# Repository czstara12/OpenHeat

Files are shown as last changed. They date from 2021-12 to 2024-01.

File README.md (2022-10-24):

# OpenHeat：开源智能加热台

# 添加&修改内容

1. 添加 [MAX6675代码](https://github.com/adafruit/MAX6675-library)，获取K型热电偶温度，可正常使用。

2. 增加外壳文件，修改自 *酒鬼橘子* 。

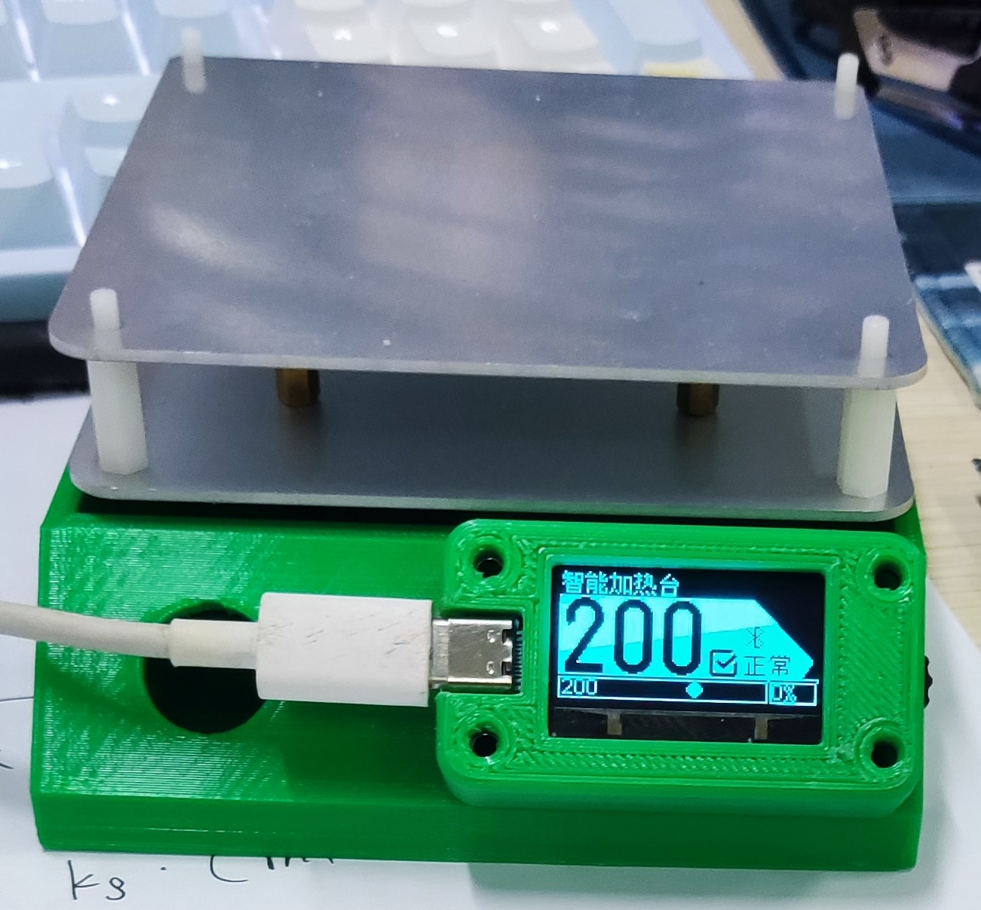
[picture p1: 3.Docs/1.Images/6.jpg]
   

3. 为配套该外壳，增加100x100的热床和中间夹层。已上传至立创EDA，方便白嫖，跳转链接为： [OpenHeat热床](https://oshwhub.com/u_16/open-heat-hot-bed) 。文件修改自 *酒鬼橘子* 。

   

   

4. 更新 [U8g2库](https://github.com/olikraus/U8g2_Arduino)，如后续仍出现无法显示，串口提示 `Bus is in Slave Mode` ，大概率是U8g2库问题，更新到最新版库即可。

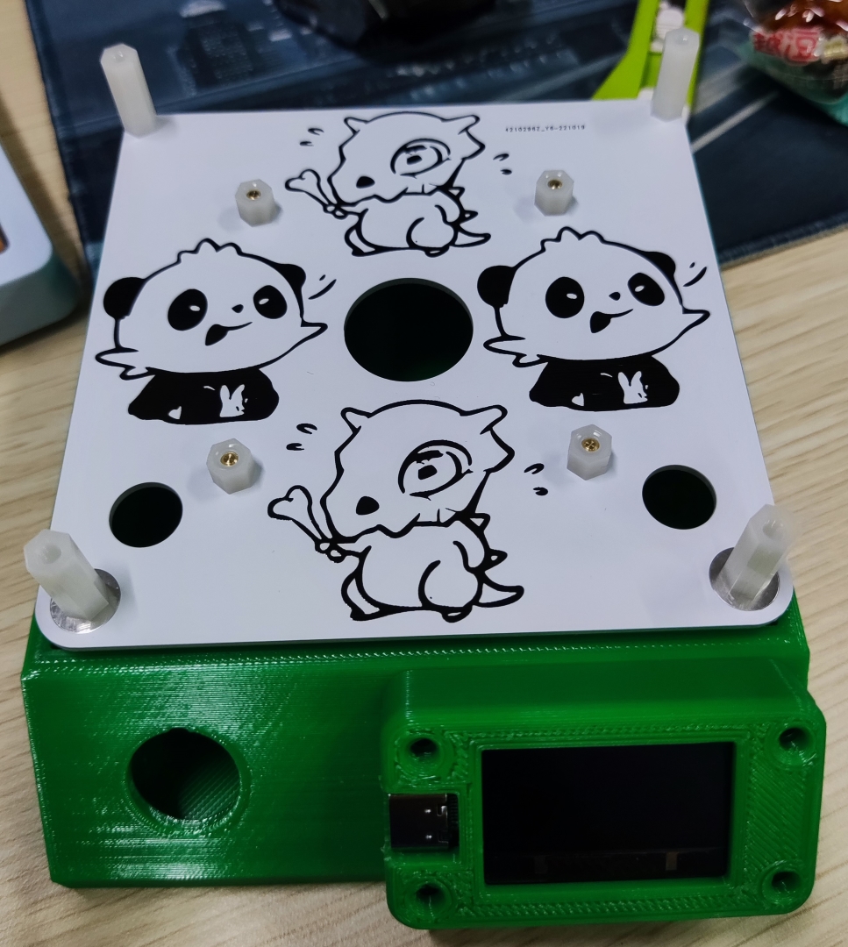
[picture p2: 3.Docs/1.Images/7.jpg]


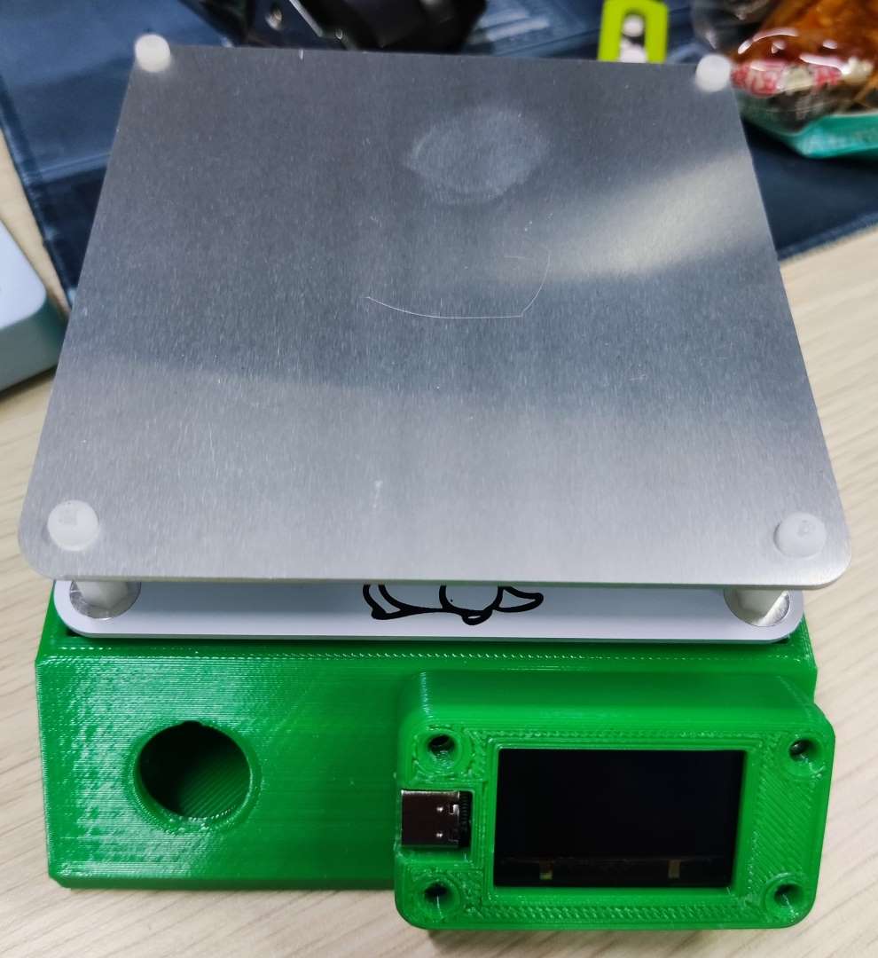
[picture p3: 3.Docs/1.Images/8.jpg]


# 以下为稚晖君原版内容

> 用于PCB回流焊的实用加热台，比较炫酷，可能目前市面上 **颜值最高** & **功能最强** 的加热台。

**参数：** 硬件方面基于`ESP32PICO-D4`芯片，输入电源`24V/10A`，最大功率200W，加热温度最高300℃；带蓝牙功能，***后续有空的话我会开发手机APP用于设置升温曲线*** 。

## 21-9-17 修复说明：



---

## 关于本项目



* 本项目参考了 [createskyblue](https://gitee.com/createskyblue) / [OpenT12](https://gitee.com/createskyblue/OpenT12)开源T12电烙铁项目的固件，感谢这位同学设计的优秀交互动画体验，UI设计深得我心哈哈~

* 另外铝基板热床的设计采用了[MRobot-Origin](https://github.com/MRobot-Origin)/ [GS_Hbed](https://github.com/MRobot-Origin/GS_Hbed)同学的分型曲线设计，非常有创意~

## 使用说明

#### 1. 打样说明

直接用Hardware文件夹里的Gerber文件打样即可：主控制器为4层PCB，无特殊工艺要求；热床为铝基板PCB，可以在嘉立创打样。

> 铝基板是一种专门用来散热的PCB板材，大家看到的很多大功率LED灯珠就是这种，前阵子嘉立创开放了铝基板打样业务，还很便宜。所以相比于设计一个金属块做热床，这种方式不但成本低而且美观实用。

另外其实还有一块可选两层板作为固定件的，这个我还没来得及设计，也很简单，大家可以根据自己情况画一个，或者直接3D打印结构件固定也行。

#### 2. 固件说明

固件我这边是基于PlatformIO移植的，所以大家用这个平台的话直接打开下载就行了；如果是用Arduino IDE的话，先安装Library里面的库文件，然后一样下载。

固件库没有完全配置完成（因为原版固件是设计为电烙铁使用的），晚些我硬件都就位了会调试好固件供大家直接下载。

#### 3. 关于结构件

这个我也还在设计，我的风格肯定是以美观小巧为主，大家可以等我放出3D打印文件。

#### 4. 关于温度传感器

我这边是用的是K型热电偶，在PCB上已经集成了采集芯片，需要自己买一个表贴式的K型热电偶连接到板子下方的两个焊盘。

> 注意热电偶和热床的接触要绝缘，用高温胶带隔一下就行。另外热电偶是有极性的，如果发现加热后温度反而下降说明接反了。
>
> 现在代码中还没有加热电偶的代码，晚一点有空了会调好完整固件。大家自己添加也很容易，MAX6675使用SPI驱动，Arduino平台有很多例程。

#### 5. 关于元器件BOM

**注意！！！** C9电容一定要选耐压足够的，因为是并联到24V的VCC上，如果耐压不够短路的话可以看到烟花！！

#### 接线图



## 欢迎star支持 :D









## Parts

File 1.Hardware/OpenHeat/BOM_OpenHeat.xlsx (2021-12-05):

Comment | Description | Designator | Footprint | LibRef | Quantity
OLED-12864 | 显示屏 | 1 | OLED-12864-1.3-TOP | OLED-12864 | 1
RAINSUN |  | A1 | ANT-Rainsun-AN5120 | ANT-Rainsun-AP5120 | 1
10uF | Capacitor | C1, C8, C9, C12, C16, C18 | CAP_0402 | 电容-0402 | 6
0.1uF | Capacitor | C2, C3, C5, C7, C10, C11, C17 | CAP_0402 | 电容-0402 | 7
100pF | Capacitor | C4 | CAP_0402 | 电容-0402 | 1
100uF | Capacitor | C6 | 1206-CAP | 电容-1206 | 1
10nF | Capacitor | C13 | CAP_0402 | 电容-0402 | 1
1uF | Capacitor | C14, C15, C19 | CAP_0402 | 电容-0402 | 3
270pF | Capacitor | C20 | CAP_0402 | 电容-0402 | 1
SS54 | Diode | D1 | DO-214AC | Diode_SMA | 1
SMBJ28CA |  | D2 | SMBJ-CA_MFG | SMBJ28CA | 1
二极管-5819W | 40V | D3, D4, D5 | SOD-323 | 二极管-5819W | 3
6.8uH |  | L1 | IND-201612 | 电感-201612 | 1
BC847BVC-7 |  | Q1 | SOT563-6 | BC847BVC-7 | 1
NTMFS5C628NLT | MOSFET N-CH 60V SO8FL | Q2, Q4, Q5 | SO8FL | NTMFS5C628NLT | 3
AO3400A | N-MOS | Q3 | SOT23-3 | AO3400A | 1
10K | Resistor | R1, R3, R5, R9, R13, R14, R18, R19, R20, R21, R26, R27, R28, R29 | RES_0402 | 电阻-0402 | 14
0R | Resistor | R2, R22 | RES_0402 | 电阻-0402 | 2
100R | Resistor | R4 | RES_0402 | 电阻-0402 | 1
1.8K | Resistor | R6 | RES_0402 | 电阻-0402 | 1
12K | Resistor | R7, R10 | RES_0402 | 电阻-0402 | 2
1M | Resistor | R8, R24 | RES_0402 | 电阻-0402 | 2
5.1K | Resistor | R11, R12 | RES_0402 | 电阻-0402 | 2
1K | Resistor | R15, R30 | RES_0402 | 电阻-0402 | 2
2.2R | Resistor | R16, R23, R31 | RES_0402 | 电阻-0402 | 3
100K | Resistor | R17, R25, R32 | RES_0402 | 电阻-0402 | 3
Rotary Encoder |  | SW1 | SIQ-02FVS3 | Rotary Encoder | 1
CP2102 | USB转TTL | U1 | QFN-28 | CP2102 | 1
ME3116 | DC-DC | U2 | SOT23-6 | ME3116 | 1
LP2992 3V3 | LDO | U3 | SOT23-5 | LP2992 | 1
ESP32_SIP |  | U4 | QFN-48_7X7 | ESP32-PICO | 1
MAX6675ISA | IC THERMOCOUP TO DGTL 8-SOIC | U5 | SO-8 | MAX6675ISA | 1
DET402 |  | U6 | DET402 | DET402 | 1
Type-C |  | USB1 | Type-C-TOP | USB-Type-C-TOP | 1
S8050 | Surface mount NPN transistor, package SOT-23 | VT1 | SMT_TRIODE_NPN | SMT_TRIODE_NPN | 1

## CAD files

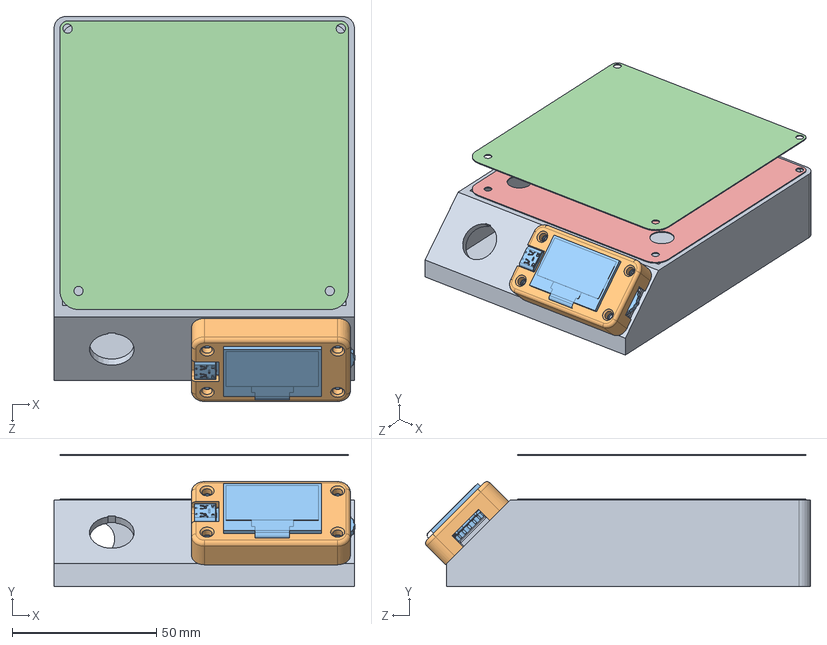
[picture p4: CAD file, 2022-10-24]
4.CAD-Model/OPEN HEAT加热台/OPEN HEAT装配体.SLDASM
104.2 x 45.8 x 133.3 mm
OPEN HEAT主体
OPEN HEAT控制器外壳
OpenHeat
100mm²HotBeb
中间层

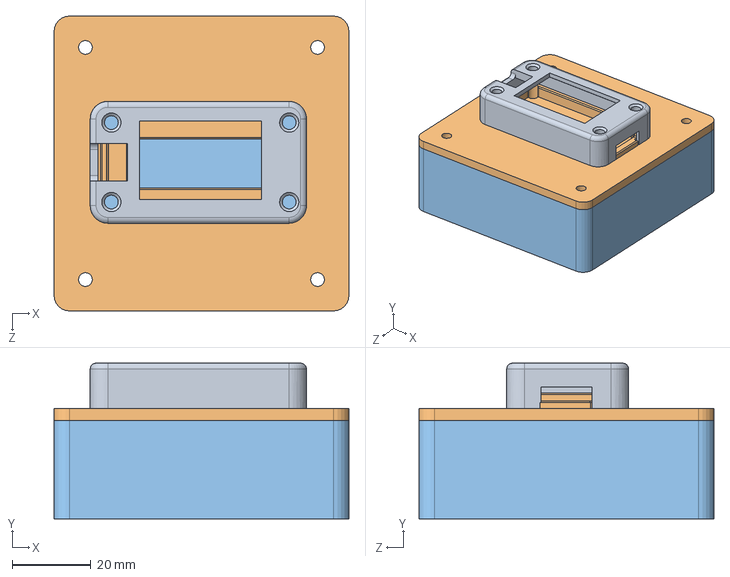
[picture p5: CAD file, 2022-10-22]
4.CAD-Model/温控外壳/控制器壳装配体.SLDASM
75.0 x 39.6 x 75.0 mm
控制器壳座
线夹

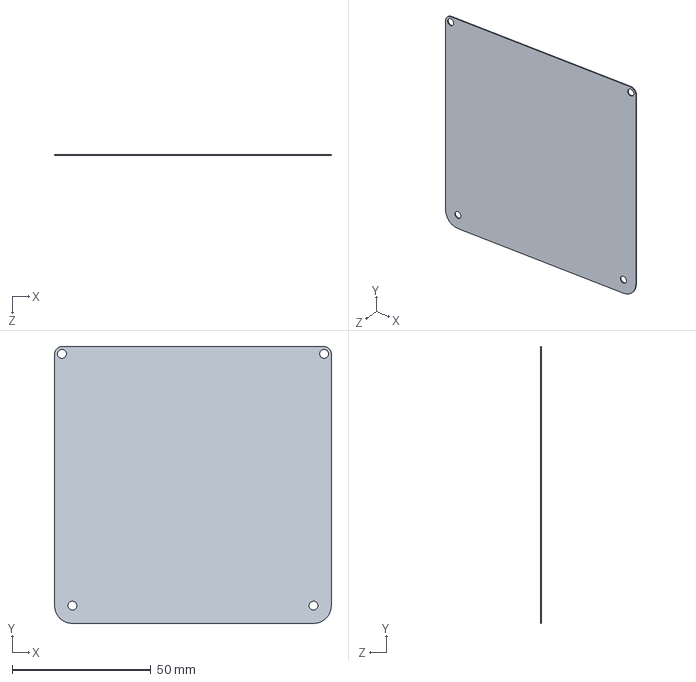
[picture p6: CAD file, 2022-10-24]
4.CAD-Model/PCB_3D/100mm²HotBeb.SLDPRT
99.9 x 99.9 x 0.411 mm

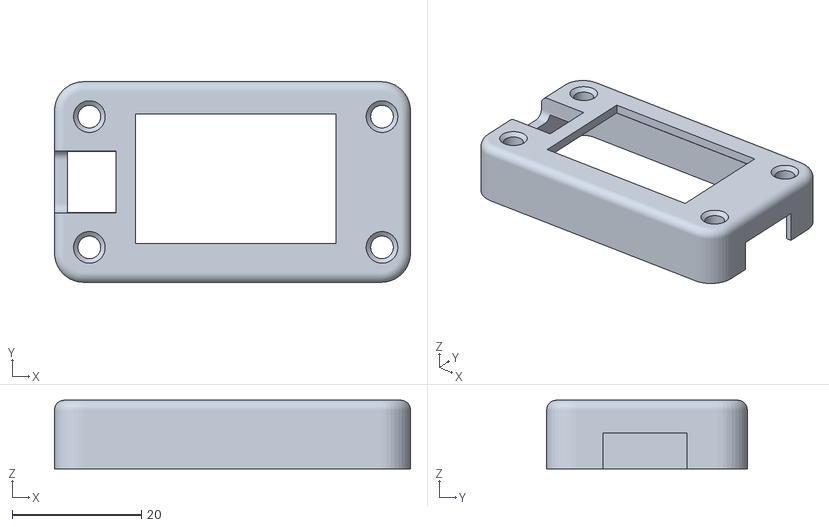
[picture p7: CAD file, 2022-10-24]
4.CAD-Model/STL/OPEN HEAT控制器外壳.STL
55.0 x 31.0 x 10.6

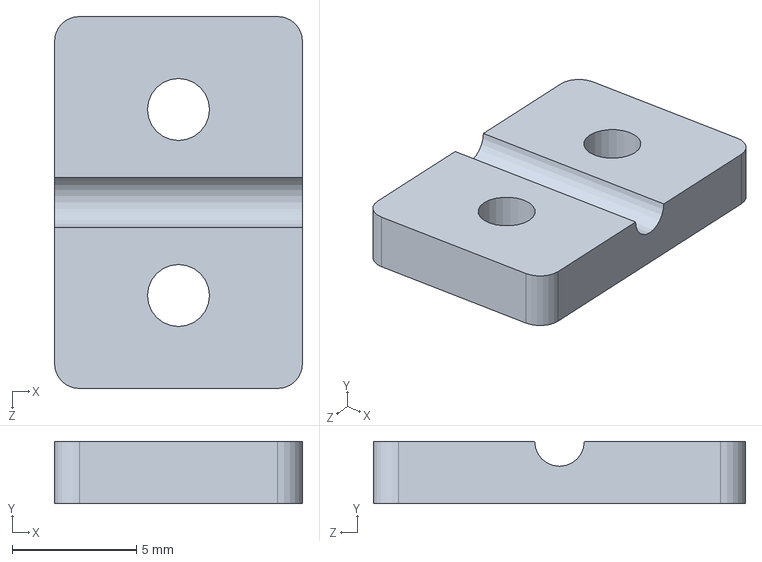
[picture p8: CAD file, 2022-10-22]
4.CAD-Model/温控外壳/线夹.SLDPRT
10.0 x 2.50 x 15.0 mm

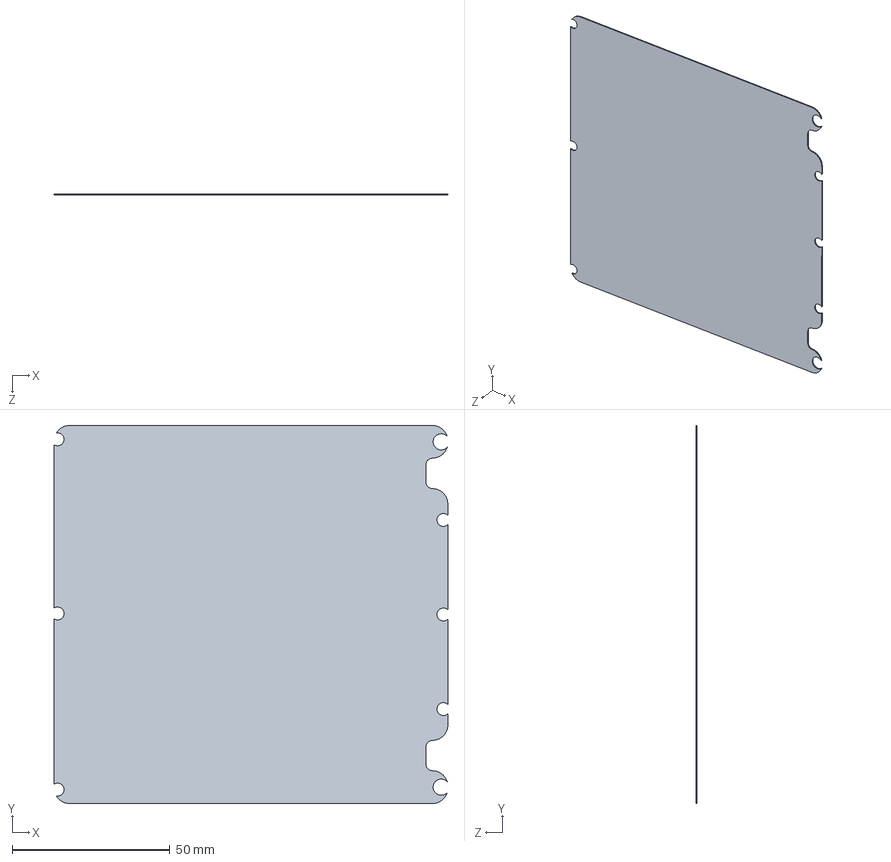
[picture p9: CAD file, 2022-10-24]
4.CAD-Model/PCB_3D/HotBed-24V_修改.SLDPRT
125.0 x 120.0 x 0.411 mm

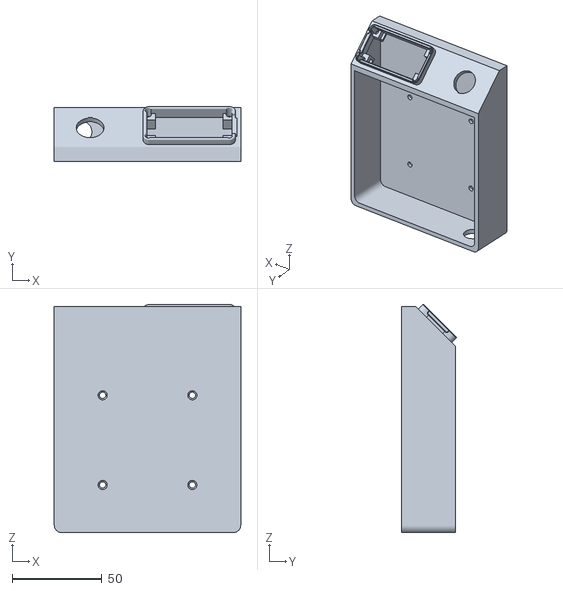
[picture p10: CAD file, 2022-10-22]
4.CAD-Model/STL/OPEN HEAT主体.STL
104.0 x 30.6 x 127.1

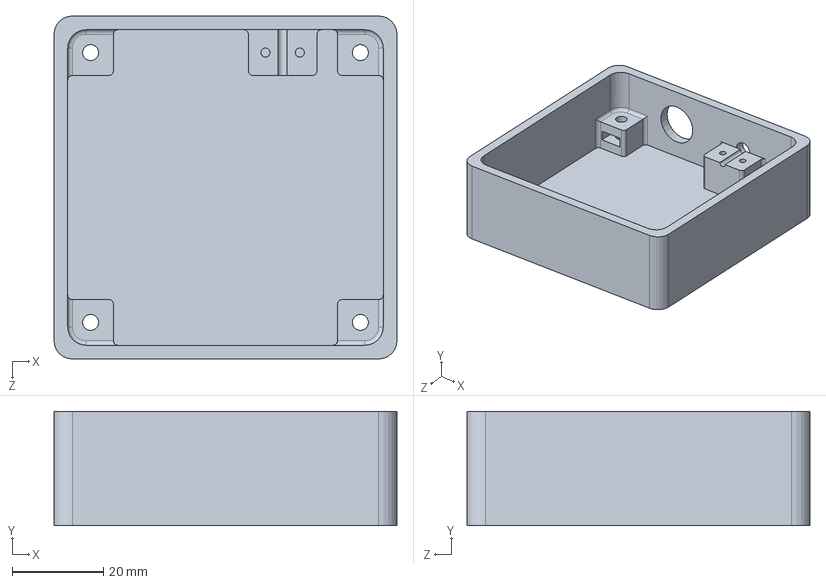
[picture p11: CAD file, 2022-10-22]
4.CAD-Model/温控外壳/控制器壳座.SLDPRT
75.0 x 25.0 x 75.0 mm

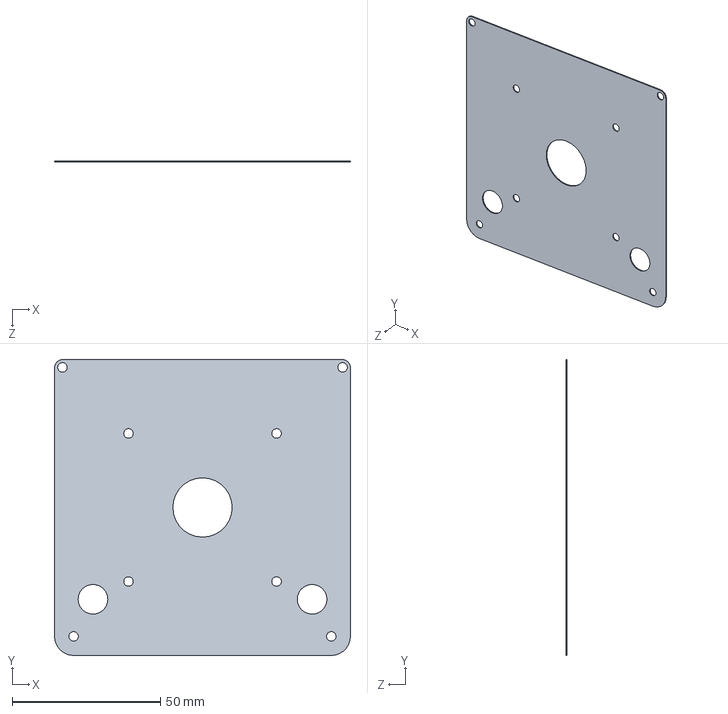
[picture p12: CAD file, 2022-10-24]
4.CAD-Model/PCB_3D/中间层.SLDPRT
99.9 x 99.9 x 0.411 mm

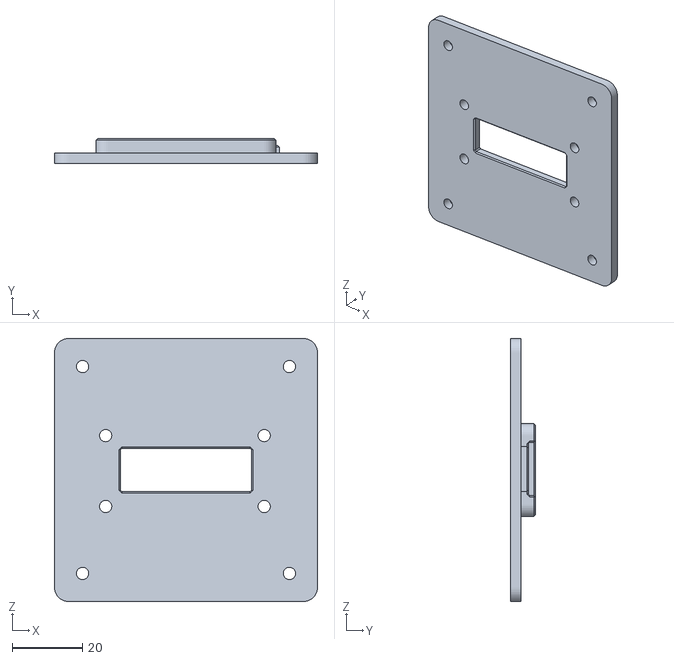
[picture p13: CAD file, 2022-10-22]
4.CAD-Model/STL/控制器壳盖.STL
75.0 x 7.00 x 75.0

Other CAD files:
4.CAD-Model/OPEN HEAT加热台/OPEN HEAT控制器外壳.SLDPRT
4.CAD-Model/OPEN HEAT加热台/OPEN HEAT主体.SLDPRT
4.CAD-Model/温控外壳/控制器壳盖.SLDPRT
4.CAD-Model/STL/线夹.STL
4.CAD-Model/STL/控制器壳座.STL

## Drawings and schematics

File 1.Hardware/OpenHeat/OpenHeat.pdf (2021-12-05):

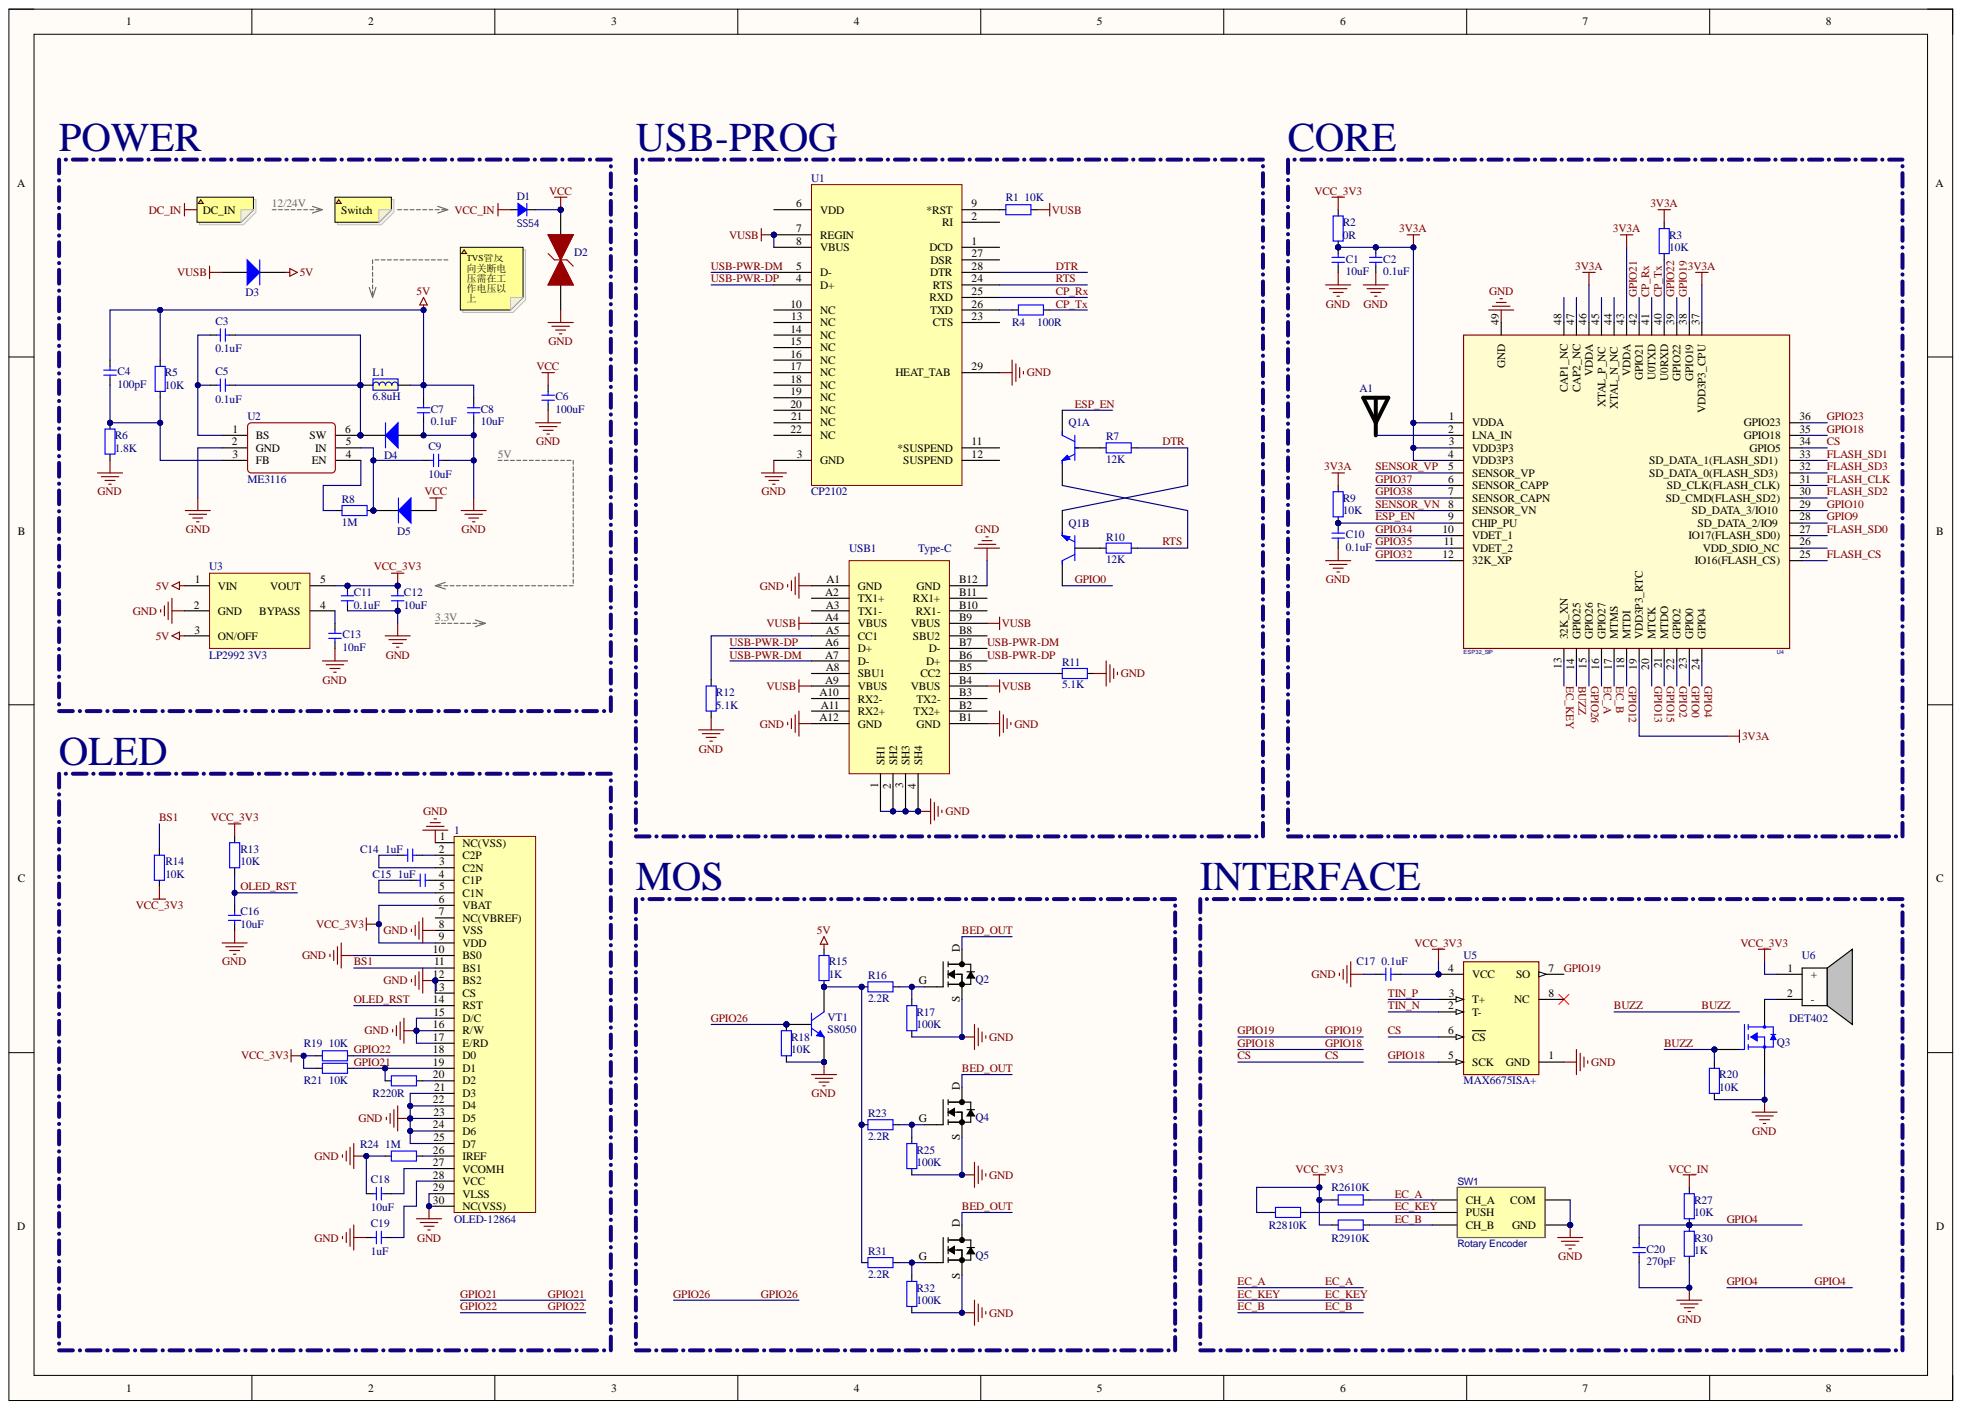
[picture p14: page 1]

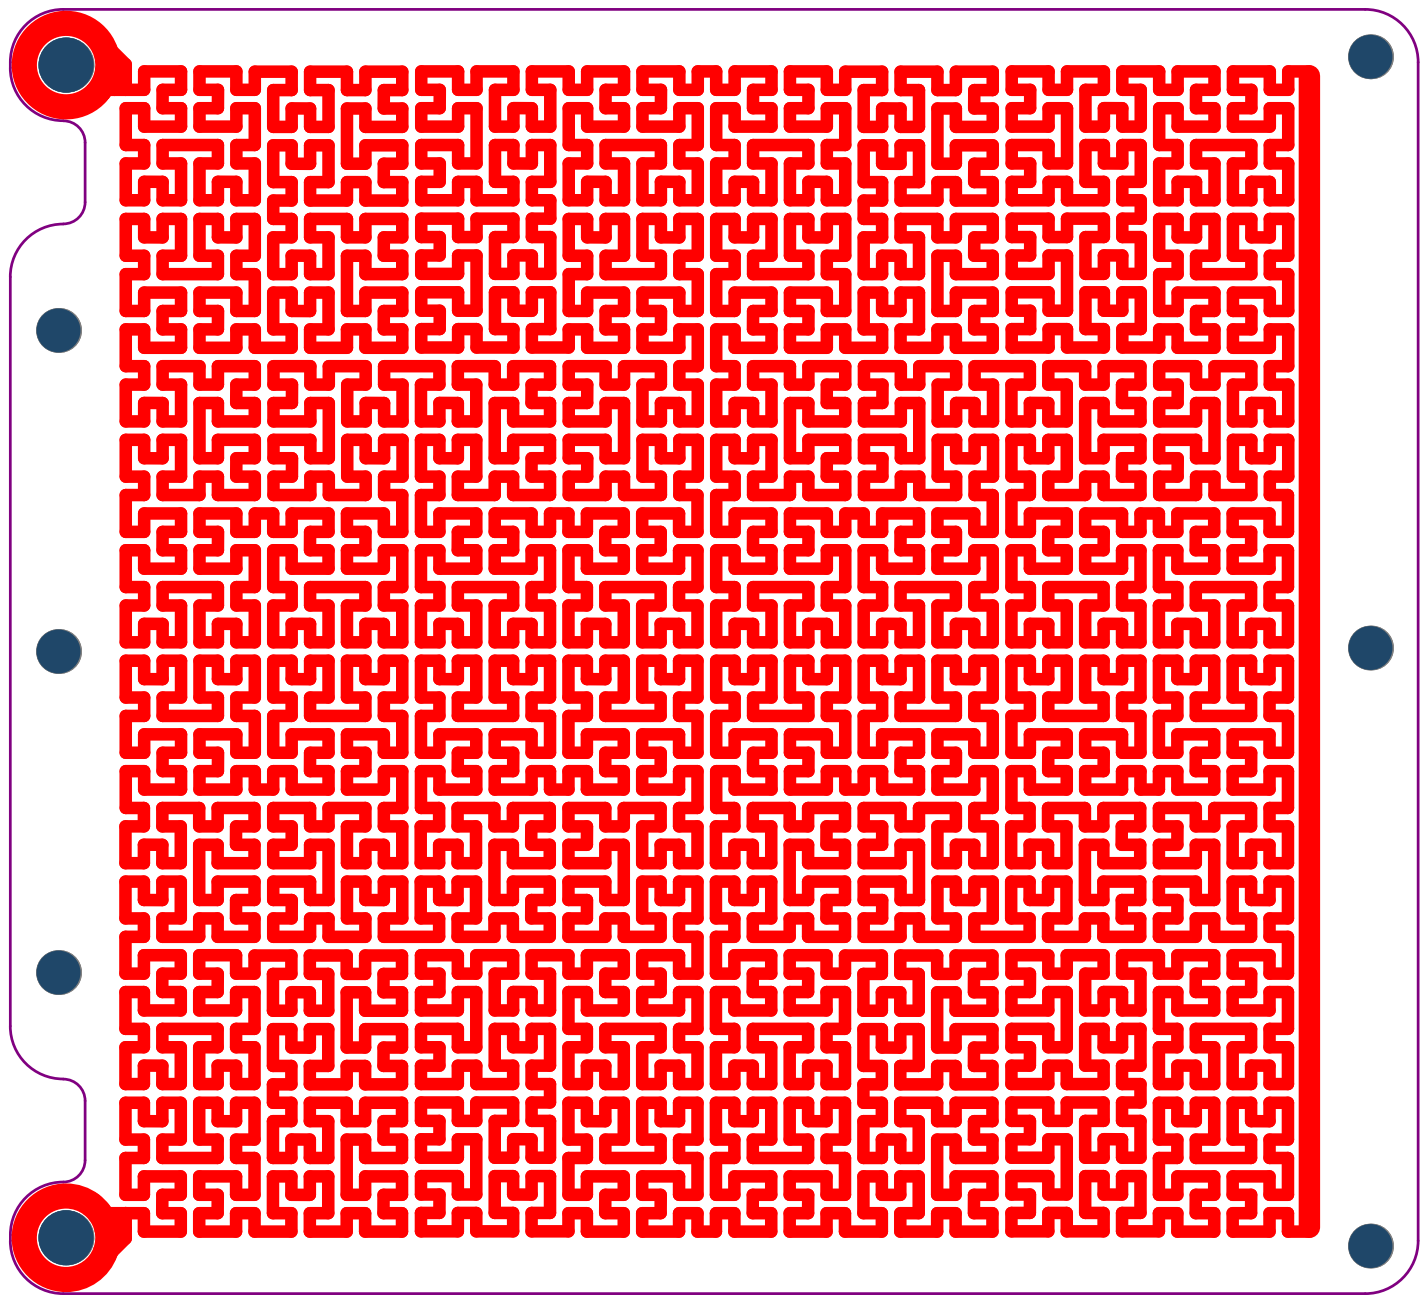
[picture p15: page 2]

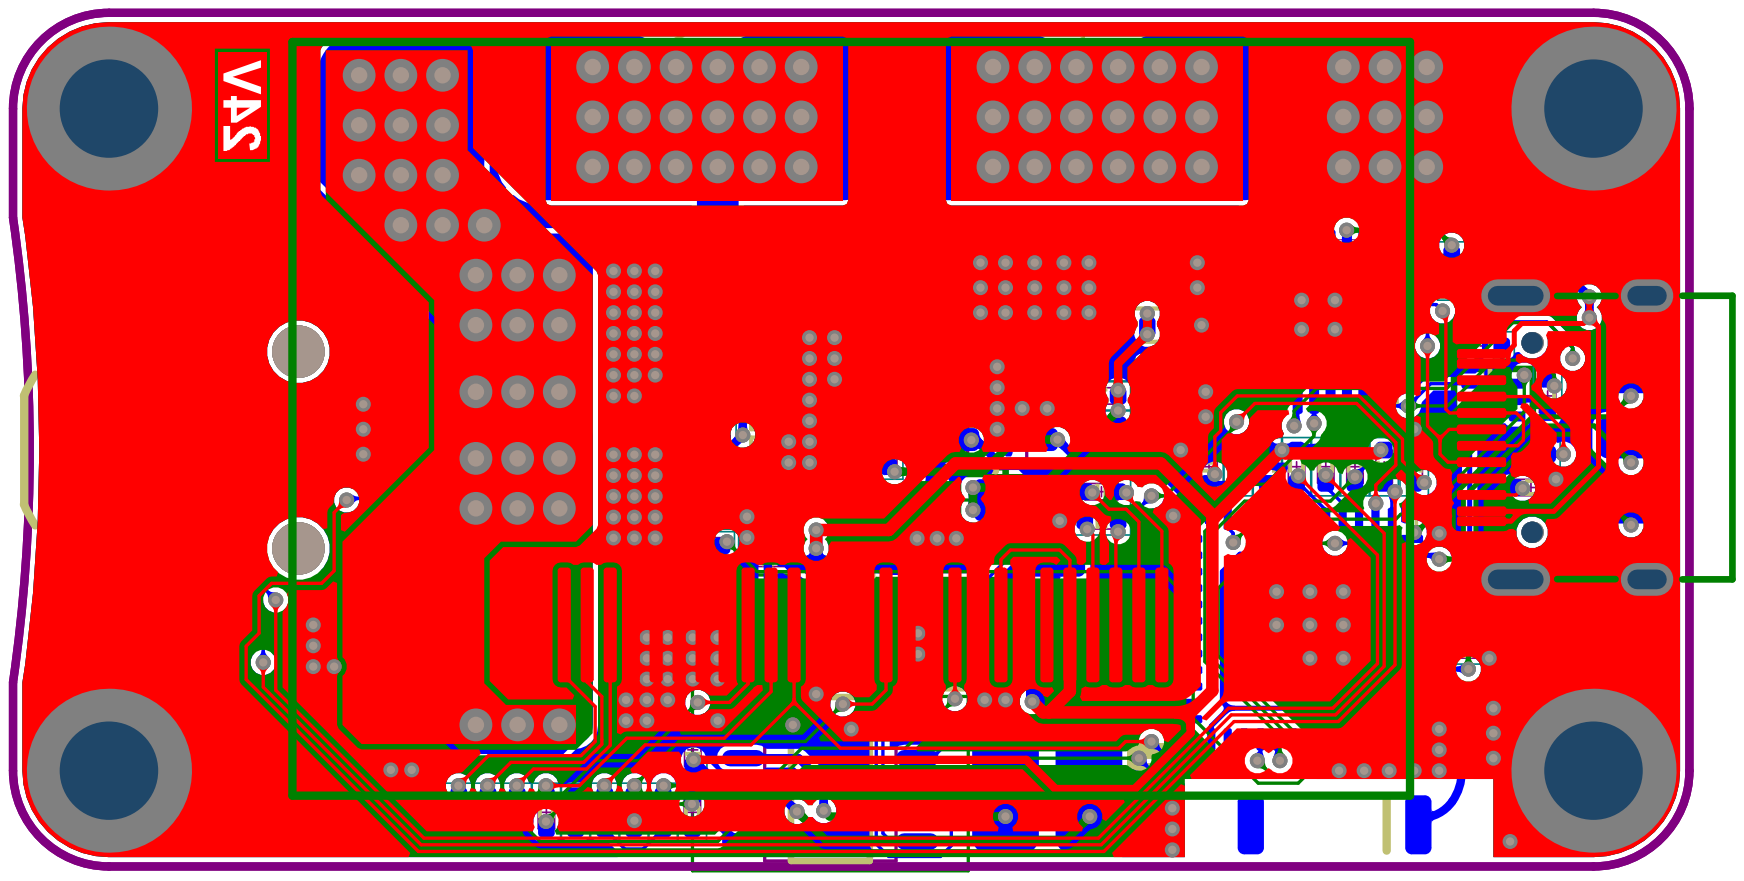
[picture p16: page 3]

Comment | Description | Designator | Footprint | LibRef | Quantity
OLED-12864 | 显示屏 | 1 | OLED-12864-1.3-TOP | OLED-12864 | 1
RAINSUN | | A1 | ANT-Rainsun-AN5120 | ANT-Rainsun-AP5120 | 1
10uF | Capacitor | C1, C8, C9, C12, C16, C18 | CAP_0402 | 电容-0402 | 6
0.1uF | Capacitor | C2, C3, C5, C7, C10, C11, C17 | CAP_0402 | 电容-0402 | 7
100pF | Capacitor | C4 | CAP_0402 | 电容-0402 | 1
100uF | Capacitor | C6 | 1206-CAP | 电容-1206 | 1
10nF | Capacitor | C13 | CAP_0402 | 电容-0402 | 1
1uF | Capacitor | C14, C15, C19 | CAP_0402 | 电容-0402 | 3
270pF | Capacitor | C20 | CAP_0402 | 电容-0402 | 1
SS54 | Diode | D1 | DO-214AC | Diode_SMA | 1
SMBJ28CA | | D2 | SMBJ-CA_MFG | SMBJ28CA | 1
二极管-5819W | 40V | D3, D4, D5 | SOD-323 | 二极管-5819W | 3
6.8uH | | L1 | IND-201612 | 电感-201612 | 1
BC847BVC-7 | | Q1 | SOT563-6 | BC847BVC-7 | 1
NTMFS5C628NLT | MOSFET N-CH 60V SO8FL | Q2, Q4, Q5 | SO8FL | NTMFS5C628NLT | 3
AO3400A | N-MOS | Q3 | SOT23-3 | AO3400A | 1
10K | Resistor | R1, R3, R5, R9, R13, R14, R18, R19, R20, R21, R26, R27, R28, R29 | RES_0402 | 电阻-0402 | 14
0R | Resistor | R2, R22 | RES_0402 | 电阻-0402 | 2
100R | Resistor | R4 | RES_0402 | 电阻-0402 | 1
1.8K | Resistor | R6 | RES_0402 | 电阻-0402 | 1
12K | Resistor | R7, R10 | RES_0402 | 电阻-0402 | 2
1M | Resistor | R8, R24 | RES_0402 | 电阻-0402 | 2
5.1K | Resistor | R11, R12 | RES_0402 | 电阻-0402 | 2
1K | Resistor | R15, R30 | RES_0402 | 电阻-0402 | 2
2.2R | Resistor | R16, R23, R31 | RES_0402 | 电阻-0402 | 3
100K | Resistor | R17, R25, R32 | RES_0402 | 电阻-0402 | 3
Rotary Encoder | | SW1 | SIQ-02FVS3 | Rotary Encoder | 1
CP2102 | USB转TTL | U1 | QFN-28 | CP2102 | 1
ME3116 | DC-DC | U2 | SOT23-6 | ME3116 | 1
LP2992 3V3 | LDO | U3 | SOT23-5 | LP2992 | 1
ESP32_SIP | | U4 | QFN-48_7X7 | ESP32-PICO | 1
MAX6675ISA | IC THERMOCOUP TO DGTL 8-SOIC | U5 | SO-8 | MAX6675ISA | 1
DET402 | | U6 | DET402 | DET402 | 1
Type-C | | USB1 | Type-C-TOP | USB-Type-C-TOP | 1
S8050 | Surface mount NPN transistor, package SOT-23 | VT1 | SMT_TRIODE_NPN | SMT_TRIODE_NPN | 1

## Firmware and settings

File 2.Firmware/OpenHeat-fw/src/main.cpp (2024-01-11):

#include <Arduino.h>
#include "OpenT12.h"

BluetoothSerial SerialBT;
#if !defined(CONFIG_BT_ENABLED) || !defined(CONFIG_BLUEDROID_ENABLED)
#error Bluetooth is not enabled! Please run `make menuconfig` to and enable it
#endif

int thermoDO = 19;
int thermoCS = 5;
int thermoCLK = 18;

MAX6675 thermocouple(thermoCLK, thermoCS, thermoDO);
OneButton RButton(BUTTON_PIN, true);
U8G2_SH1106_128X64_NONAME_F_HW_I2C Disp(U8G2_R0, /* reset=*/U8X8_PIN_NONE, /* clock=*/22, /* data=*/21);
PID MyPID(&TipTemperature, &PID_Output, &PID_Setpoint, aggKp, aggKi, aggKd, DIRECT);
/////////////////////////////////////////////////////////////////

char *TipName = "文件系统错误：请上报";

float BootTemp = 200; // 开机温度          (°C)
float SleepTemp = 80; // 休眠温度          (°C)
float BoostTemp = 50; // 爆发模式升温幅度   (°C)

float ShutdownTime = 0;         // 关机提醒              (分)
float SleepTime = 10;           // 休眠触发时间          (分)
float ScreenProtectorTime = 60; // 屏保在休眠后的触发时间(秒)
float BoostTime = 60;           // 爆发模式持续时间      (秒)

bool SYS_Ready = false;
// 烙铁头事件
bool TipInstallEvent = true;
bool TipCallSleepEvent = false;
// 到温提示音播放完成
bool TempToneFlag = false;
// 休眠后屏保延迟显示标志
bool SleepScreenProtectFlag = false;
// 温控系统状态
bool ERROREvent = false;
bool ShutdownEvent = false;
bool SleepEvent = false;
bool BoostEvent = false;
bool UnderVoltageEvent = false;
// PWM控制状态
bool PWM_WORKY = false;

uint8_t PIDMode = true;
uint8_t Use_KFP = true;
uint8_t PanelSettings = PANELSET_Detailed;
uint8_t ScreenFlip = false;
uint8_t SmoothAnimation_Flag = true;
float ScreenBrightness = 128;
uint8_t OptionStripFixedLength_Flag = false;

uint8_t Volume = true;
uint8_t RotaryDirection = false;
uint8_t HandleTrigger = HANDLETRIGGER_VibrationSwitch;

double SYS_Voltage = 3.3;
float UndervoltageAlert = 3;
char BootPasswd[20] = {0};
uint8_t Language = LANG_Chinese;
uint8_t MenuListMode = false;

float ADC_PID_Cycle = 100;
float MAX6675Temp_Cycle = 300; // MAX6675温度采集周期

// 面板状态条
uint8_t TempCTRL_Status = TEMP_STATUS_OFF;
uint8_t *C_table[] = {c1, c2, c3, Lightning, c5, c6, c7};
char *TempCTRL_Status_Mes[] = {
    "错误",
    "停机",
    "休眠",
    "提温",
    "正常",
    "加热",
    "维持",
};

// 系统信息
uint64_t ChipMAC;
char ChipMAC_S[19] = {0};
char CompileTime[20];

/////////////////////////////////////////////////////////////////

// 先初始化硬件->显示LOGO->初始化软件
void setup()
{
    // 关闭中断
    // noInterrupts();

    ////////////////////////////初始化硬件/////////////////////////////
    // 获取系统信息
    ChipMAC = ESP.getEfuseMac();
    sprintf(CompileTime, "%s %s", __DATE__, __TIME__);
    for (uint8_t i = 0; i < 6; i++)
        sprintf(ChipMAC_S + i * 3, "%02X%s", ((uint8_t *)&ChipMAC)[i], (i != 5) ? ":" : "");

    // 初始化串口
    Serial.begin(115200);

    // 初始化GPIO
    BeepInit(); // 蜂鸣器

    pinMode(POWER_ADC_PIN, INPUT); // 主电压分压检测ADC

    // 初始化烙铁头
    TipControlInit();

    // 初始化编码器
    sys_RotaryInit();

    // 初始化OLED
    Disp.begin();
    Disp.setBusClock(921600); // 设置总线时钟
    Disp.enableUTF8Print();   // 启用 UTF8打印
    Disp.setFontDirection(0); // 设置字体方向
    Disp.setFontPosTop();
    Disp.setFont(u8g2_font_wqy12_t_gb2312); // 设置字体集
    Disp.setDrawColor(1);                   // 设置绘制颜色
    Disp.setFontMode(1);

    ////////////////////////////初始化软件/////////////////////////////
    // 显示启动信息
    // ShowBootMsg();

    // 启动文件系统，并读取存档
    FilesSystemInit();

    // 初始化命令解析器
    shellInit();

    // 初始化蓝牙（可选）
    BLE_Init();

    SetSound(BootSound); // 播放音效

    // 初始化UI
    System_UI_Init();

    // 首次启动的时候根据启动温度配置，重新设定目标温度
    sys_Counter_SetVal(BootTemp);

    // 载入烙铁头配置
    LoadTipConfig();

    // 显示Logo
    // EnterLogo();

    // 开机密码
    while (!EnterPasswd())
    {
        Pop_Windows("身份验证失败");
    }
    SYS_Ready = true;
}

void loop()
{
    // 获取按键
    sys_KeyProcess();

    if (!Menu_System_State)
    {
        // 温度闭环控制
        TemperatureControlLoop();
        // 更新系统事件：：系统事件可能会改变功率输出
        TimerEventLoop();
    }

    // 更新状态码
    SYS_StateCode_Update();
    // 设置输出功率
    SetPOWER(PID_Output);

    // 刷新UI
    System_UI();
}
/**
 * @description: 计算主电源电压
 * @param {*}
 * @return 主电源电压估计值
 */
double Get_MainPowerVoltage(void)
{
    // uint16_t POWER_ADC = analogRead(POWER_ADC_PIN);
    double TipADC_V_R2 = analogReadMilliVolts(POWER_ADC_PIN) / 1000.0;
    // double   TipADC_V_R2 = ESP32_ADC2Vol(POWER_ADC);
    double TipADC_V_R1 = (TipADC_V_R2 * POWER_ADC_VCC_R1) / POWER_ADC_R2_GND;

    SYS_Voltage = TipADC_V_R1 + TipADC_V_R2;
    return SYS_Voltage;
}

void SYS_Reboot(void)
{
    ESP.restart();
}

void About(void)
{
    // 播放Logo动画
    EnterLogo();
    // 生成项目QRCode
    QRCode qrcode;
    uint8_t qrcodeData[qrcode_getBufferSize(3)];

    switch (Language)
    {
    case LANG_Chinese:
        qrcode_initText(&qrcode, qrcodeData, 3, 0, "https://gitee.com/createskyblue/OpenT12");
        break;

    default:
        qrcode_initText(&qrcode, qrcodeData, 3, 0, "https://github.com/createskyblue/OpenT12");
        break;
    }

    Clear();

    uint8_t x_offset = (SCREEN_COLUMN - qrcode.size * 2) / 2;
    uint8_t y_offset = (SCREEN_ROW - qrcode.size * 2) / 2;

    for (uint8_t y = 0; y < qrcode.size; y++)
        for (uint8_t x = 0; x < qrcode.size; x++)
            if (qrcode_getModule(&qrcode, x, y))
                Draw_Pixel_Resize(x + x_offset, y + y_offset, x_offset, y_offset, 2, 2);

    Disp.setDrawColor(2);
    Disp.drawBox(x_offset - 2, y_offset - 2, qrcode.size * 2 + 4, qrcode.size * 2 + 4);
    Disp.setDrawColor(1);

    while (!sys_KeyProcess())
    {
        Display();
    }
}

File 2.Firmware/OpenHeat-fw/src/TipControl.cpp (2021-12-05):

#include "OpenT12.h"

//[既然有了nmos 为啥还要pmos]科普:https://www.bilibili.com/video/BV1Mb4y1k7fd?from=search&seid=15411923932488650975

enum MOS_Type
{
    PMOS = 0,
    NMOS
};
//PWM
uint8_t PWM_Freq = 2000;    // 频率
uint8_t PWM1_Channel = 0;    // 通道
uint8_t PWM2_Channel = 0;    // 通道
uint8_t PWM_Resolution = 8;   // 分辨率
//基础温控
uint8_t MyMOS = PMOS;
uint8_t POWER = 0;
uint8_t PWM = 0;
uint8_t LastPWM = 0;
uint16_t LastADC = 0;
double LastMAX6675Temp = 0;
double TipTemperature = 0;
double PID_Output = 0;
double PID_Setpoint = 0;
double TempGap = 0;
uint32_t ADCSamplingInterval = 0; //ADC采样间隔(ms)


//PID
float aggKp = 60.0, aggKi = 0, aggKd = 0.5;
float consKp = 40.0, consKi = 1, consKd = 0.5;

//初始化烙铁头温控系统
void TipControlInit(void)
{
    //初始化ADC输入GPIO
    pinMode(TIP_ADC_PIN, INPUT_PULLUP); //ADC

    ledcAttachPin(PWM1_PIN, PWM1_Channel);  // 绑定PWM1通道
    ledcSetup(PWM1_Channel, PWM_Freq, PWM_Resolution); // 设置PWM1通道

    if (PWM2_PIN != -1)
    {
        ledcAttachPin(PWM2_PIN, PWM2_Channel);  // 绑定PWM2通道
        ledcSetup(PWM2_Channel, PWM_Freq, PWM_Resolution); // 设置PWM2通道
    }

    SetPOWER(0); //关闭功率管输出

    if (SW_PIN != -1)
    {
        //初始化SW-PIN休眠检测引脚
        pinMode(SW_PIN, INPUT_PULLUP);
        //初始化SW-PIN休眠检测引脚中断 (尽可能减少中断的使用)
        //attachInterrupt(SW_PIN, SW_IRQHandler, CHANGE);
    }

    //初始化烙铁头PID
    MyPID.SetOutputLimits(0, 255); //PID输出限幅
    MyPID.SetMode(AUTOMATIC); //PID控制模式
    MyPID.SetSampleTime(10); //PID采样时间
}

//计算实际温度
double CalculateTemp(double ADC, double P[])
{
    //TipTemperature = P[0] + ADC * P[1] + ADC * ADC * P[2] + ADC * ADC * ADC * P[3];
    return TipTemperature;
}

//PWM输出模块
uint8_t PWMOutput_Lock = true;
void PWMOutput(uint8_t pwm)
{
    PWM_WORKY = true;
    //PWM锁
    if (PWMOutput_Lock || ShutdownEvent || Menu_System_State || ERROREvent)
    {
        PWM_WORKY = false;
        // Log(LOG_INFO,"输出被限制");
        // printf("输出被限制 PWMOutput_Lock=%d ShutdownEvent=%d Menu_System_State=%d ERROREvent=%d\n", PWMOutput_Lock, ShutdownEvent, Menu_System_State, ERROREvent);
        if (MyMOS == PMOS) pwm = 255;
        else pwm = 0;

        // //软件指示灯
        // digitalWrite(LED_Pin ,LOW);
    }
    //printf("PWM:%d\n",pwm);
    if (LastPWM != pwm)
    {
        if (pwm == 255) ledcWrite(PWM1_Channel, 256);
        else ledcWrite(PWM1_Channel, pwm);

        LastPWM = pwm;
    }

}

/**
 *调用卡尔曼滤波器 实践
 */
KFP KFP_Temp = {0.02, 0, 0, 0, 0.01, 4.5};
float SamplingRatioWork = 10;           //采样/加热 比率
//获取ADC读数
int GetADC0(void)
{
    static uint32_t ADCSamplingTime = 0; //上次采样时间
    static uint32_t ADCReadCoolTimer = 0;

    if (SYS_Ready)
    {

        ADCSamplingInterval = millis() - ADCSamplingTime;
        if (ADCSamplingInterval < ADC_PID_Cycle * (9 / 10.0)) return LastADC; // 9/10周期ADC不应该工作，应该把时间留给加热

        //若原输出非关闭，则在关闭输出后等待一段时间，因为电热偶和加热丝是串在一起的，只有不加热的时候才能安全访问热偶温度
        if (PWMOutput_Lock == false)
        {
            ADCReadCoolTimer = millis();
            //锁定功率管输出：必须要关闭MOS管才能成功读取电热偶
            PWMOutput_Lock = true;
        }

        if (millis() - ADCReadCoolTimer <= ADC_PID_Cycle / 10)
        {
            return -1; //数据未准备好
        }

    }

    //读取并平滑滤波经过运算放大器放大后的热偶ADC数据
    uint16_t ADC_RAW = analogRead(TIP_ADC_PIN); //从引脚获取ADC值
    uint16_t ADC;

    //卡尔曼滤波器
    if (Use_KFP) ADC = kalmanFilter(&KFP_Temp, (float) ADC_RAW);
    else ADC = ADC_RAW;
    //printf("%d,%d\r\n", ADC_RAW,ADC);

    //解锁功率管输出：前提是没有打开菜单
    if (!Menu_System_State)
        PWMOutput_Lock = false;

    //记录采样间隔时间
    ADCSamplingTime = millis();

    LastADC = ADC;
    return LastADC;
}

// 获取获取MAX6675的温度数据
double GetMAX6675Temp()
{
    static uint32_t MAX6675TempSamplingTime = 0; //上次采样时间
    uint32_t MAX6675TempSamplingInterval = 0; //MAX6675温度采样间隔(ms)

    if (SYS_Ready)
    {

        MAX6675TempSamplingInterval = millis() - MAX6675TempSamplingTime;
        if (MAX6675TempSamplingInterval < MAX6675Temp_Cycle) return LastMAX6675Temp; //MAX6675温度采样间隔 未到达  设定周期

    }

    //获取MAX6675的温度数据
    float MAX6675Temp;
    MAX6675Temp = thermocouple.readCelsius();

    //记录采样间隔时间
    MAX6675TempSamplingTime = millis();
    LastMAX6675Temp = MAX6675Temp;

    return LastMAX6675Temp;
}

//设置输出功率
void SetPOWER(uint8_t power)
{

    POWER = power;
    //MOS管分类处理
    if (MyMOS == PMOS)
    {
        //PMOS 低电平触发
        PWM = 255 - power;
    }

    PWMOutput(PWM);
}

float ADC_PID_Cycle_List[3] = {200, 100, 50};
//温度控制循环
void TemperatureControlLoop(void)
{
    Clear();
    char buffer[50];
    int ADC;

    PID_Setpoint = sys_Counter_Get();
    if (BoostEvent)
    {
        //短时功率加成
        PID_Setpoint += BoostTemp;
    } else if (SleepEvent) //睡眠模式
    {
        PID_Setpoint = SleepTemp;
    }

    PID_Setpoint = constrain(PID_Setpoint, TipMinTemp, TipMaxTemp); //限定PID上下限
    //尝试访问ADC
    //ADC = GetADC0();
    
    //尝试获取温度
    TipTemperature = GetMAX6675Temp();
    if (TipTemperature > 0/*ADC != -1*/)
    {

        //TipTemperature = CalculateTemp((double) LastADC, PTemp); //计算实际温度
        TempGap = abs(PID_Setpoint - TipTemperature);  //实际温度与设定温度的差值

        //根据温差选择合适的ADC-PID采样周期
        if (TempGap > 150) ADC_PID_Cycle = ADC_PID_Cycle_List[0];
        else if (TempGap > 50) ADC_PID_Cycle = ADC_PID_Cycle_List[1];
        else ADC_PID_Cycle = ADC_PID_Cycle_List[2];

        /////////////////////////////////////////////////////////////////////////////////////////////
        //控温模式
        if (PIDMode)
        {
            //PID模式

            //根据温度差选择最优的PID配置，PID参数可被Shell实时更改
            if (TempGap < 30) MyPID.SetTunings(consKp, consKi, consKd);
            else MyPID.SetTunings(aggKp, aggKi, aggKd);
            //更新PID采样时间：采样时间可被Shell实时更改
            //MyPID.SetSampleTime(PIDSampleTime);
            MyPID.SetSampleTime(ADC_PID_Cycle); //设置采样时间  设置执行计算的时间段（以毫秒为单位）

            //尝试计算PID
            //printf("计算PID：%d\n PID输出:%lf", MyPID.Compute(), PID_Output);
            MyPID.Compute();

        } else
        {
            //模糊模式
            if (TipTemperature < PID_Setpoint) PID_Output = 255;
            else PID_Output = 0;
        }


        //串口打印温度
        //printf("Temp:%lf,%lf,%d\r\n", TipTemperature, PID_Setpoint, ADC);
        printf("Temp:%lf\r\n", TipTemperature);

        /////////////////////////////////////////////////////////////////////////////////////////////
    }
}

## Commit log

2021-12-05 修改代码，MAX6675可正常获取温度
    [BOM_OpenHeat.xlsx, HotBed-24V_修改.PcbDoc, Main.SchDoc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]
2022-10-22 增加外壳、热床
    1. 增加外壳文件。
    2. 增加配套热床。
    3. 更新U8g2库。
    [100mm²HotBeb.PcbDoc, HotBed-24V_修改.PcbDoc, HotBed-24V_修改.SLDPRT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]
2022-10-22 更新模型
    [OPEN HEAT控制器外壳.SLDPRT, OPEN HEAT控制器外壳.STL]
2022-10-22 更新 立创EDA 链接
2022-10-24 更新外壳
    [100mm²HotBeb.SLDPRT, HotBed-24V_修改.SLDPRT, OPEN HEAT控制器外壳.SLDPRT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]
2022-10-24 更新图片
2024-01-11 修改屏驱 关闭导致错误的中断 清理个人配置文件和构建文件
